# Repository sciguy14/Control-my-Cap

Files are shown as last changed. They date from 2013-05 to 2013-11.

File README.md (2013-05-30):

CONTROL MY CAP
==============
Learn more about this system on my website: http://www.jeremyblum.com/portfolio/control-my-cap  
Watch a video demo of this system: http://www.youtube.com/watch?v=23_6IZ159EQ  
  
These are the open design files for my "Control My Cap" project, which enable crowd control of a high-intensity LED array mounted on my mortar board for my graduation from the Masters in Electrical and Computer Engineering Program at Cornell University.
  
The system is setup as follows:  
* A mobile-optimized website built using Jquery Mobile UI & a Python/MySQL backend sits on a cloud server.
* People visit the website and enter a twitter handle or name, plus a color (chosen from a palet).
* After picking a color, ajax calls are used to pass the information to a python script on the server via JSON messages.
* The python script on the cloud server adds information about the color request (ID, time, name, twitter_ID, and color) to a MySQL database that resides on the same cloud server.
* The graduate (that's me) is equipped with a 15V rechargable laptop battery, a high-intensity LED cap fixture, and a Raspberry Pi computer + LCD/button "Pi Plate" (the Wrist Interface)
* The Wrist interface is strapped to the graduate's wrist, and uses the LCD to show system status.  Operation modes can be adjusted with buttons on the unit.  The Wrist controller is running [Linux Occidentalis v0.2](http://learn.adafruit.com/adafruit-raspberry-pi-educational-linux-distro/occidentalis-v0-dot-2).  It also has a Wifi USB dongle, and a USB-Serial Adapter attached.
* The USB-Serial adapter cable runs up the sleeve from the Wrist Computer to the LED array on the cap to send control commands (the cap runs an ATmega listening for Serial commands).
* Power runs from the wrist computer to the laptop battery pack where a 5V regulated supply is available.
* The battery pack is in a small drawstring backpack. It sends power the to wrist interface (5V), and up to the cap (15V).
* The wrist interface auto-runs a control program on boot.  It constantly checks the remote MySQL database, and updates its internal queue when the MySQL database gets updated.  The queue is then used to send color commands to the cap. When a new color is received, and it has not been tweeted yet, the wrist computer sends out a tweet and updates the database state variable.
  
Note:  I am opening as many files as I can.  Part of my design utilizes firmware and electronics from a another project of mine that I cannot (yet) open source.  You can sign up to learn more about it here: http://www.sunnlight.com.  

Included Folders and Repo Contents
----------------------------------
### /3D_printed_cap_holder
These are the 3D-printed design files for the mechanical PCB holder that sits on my head.
### /3D_printed_wrist_mount
These are the 3D-printed design files for the wrist-mounting unit. This enclosure houses and protects a Raspberry Pi, as well as an Adafruit LCD Pi-Plate.
### /mobile_site
These are the files that power the www.controlmycap.com mobile site. The front end is HTML+CSS+Jquery Mobile UI. It talks to a Python/MySQL backend via JSON AJAX calls.
### /wrist_controller
These are the linux scripts that run on the Raspberry Pi that is strapped to my wrist.

License
-------
This work is licensed under a Creative Commons Attribution-ShareAlike 3.0 Unported License.  
Please share improvements or remixes with the community, and attribute me (Jeremy Blum, http://www.jeremyblum.com) when reusing portions of my code.
http://creativecommons.org/licenses/by-sa/3.0/deed.en_US

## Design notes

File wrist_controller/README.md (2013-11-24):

CONTROL MY CAP: Wrist Controller
================================
These are the files that run on the wrist computer. They coordainte the MySQL data, tweeting, controlling the LCD, reading the buttons, and sending serial commands to the light. 

Usage Notes
-----------
* I am running Linux Occidentalis v0.2 (It has I2C support already set-up).
* Place all these files in `/home/pi/cap`.
* Create a local MySQL database table called "config" with just two columns:
    * option(Varchar 16)
    * value (Varchar 16)
* In the "config" table, create three entries and load them with the defaults:
    * option = "brightness", value = "10"
	* option = "mode", value = "9"
	* option = "last_tweeted", value = "0"
* Sign up for a Twitter Dev account, and [create an API app](https://dev.twitter.com/apps).  Give it read/write access and note the `Consumer Key` and the `Consumer Secret`.
* Rename 'sample_config.py' to 'config.py' and set the variables to the information for your MySQL Schema. Set the key info for your Twitter App.
* Make sure the `pi` user has access to the i2c bus.  By default, you must be `root`. To do this, run: `sudo adduser pi i2c`. You will need to logout and login for this to take effect.
* You need to SSH into the wrist computer and run command.py one time to complete the steps for twitter OAuth authentication.  You only need to do this once.
* `/etc/rc.local` is used to initialize the system at boot.  Add the following code to `/etc/rc.local` before `exit 0` (You need to be `root` to edit this file):  

        #Init SQL database mode to "off" state
		/home/pi/cap/boot.py

		#Get the Commander Program running the in the background.
		/home/pi/cap/command.py >>/var/www/log.txt &

		#Disable RTS for USB0 Serial Device, if successful, start program
		(stty -F /dev/ttyUSB0 -hup && /home/pi/cap/cap.py) || /home/pi/cap/fail.py

First, this boot script will set the mode to "off", incase you are operating off a wifi network. Then, `rc.local` will start running the command program in the background.  It will log to a txt file that you can view from a browser on a device connected to the same network.  This is useful for spotting bugs. Then, `rc.local` will disable RTS on the USB Serial line (This prevents the cap circuit board from reseting everytime the pySerial objects connnects). If that succeeds, the main control program is started. Otherwise, the failure is indicated by the fail script.
* You will want the computer to automatically associate with a wifi network on boot. Follow [these instructions](http://www.geeked.info/raspberry-pi-add-multiple-wifi-access-points/) to install wpa-supplicant, run it in background mode at boot, and generate the pre-shared keys for your WPA-protected networks.

Necessary Packages
------------------
You will need to have the following packages installed.
* [pySerial](http://pyserial.sourceforge.net/)
* [Python MySQLdb](http://sourceforge.net/projects/mysql-python/)
* [Adafruit Raspberry Pi Libraries](https://github.com/adafruit/Adafruit-Raspberry-Pi-Python-Code) (Necessary files for I2C LCD Pi Plate Communications are already included here)
* [Python Twitter Tools](http://mike.verdone.ca/twitter/)

Attribution for Packaged Library Files
--------------------------------------
### Adafruit Python Libraries
Adafruit invests time and resources providing this open source code, please support Adafruit and open-source hardware by purchasing products from Adafruit!  
Written by Limor Fried, Kevin Townsend and Mikey Sklar for Adafruit Industries. BSD license, all text above must be included in any redistribution

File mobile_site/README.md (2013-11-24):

CONTROL MY CAP: Mobile Site
======================================
These are the files that power the mobile site.  They are running on a remote cloud server. Python 2.6 is used, and the MySQLdb library must be installed. 

Usage Notes
-----------
To use this, you will need to rename 'sample_config.py' in the cgi-bin to 'config.py' and set the variables to the information for your MySQL Schema.  
  
You should have a MySQL database table setup as follows:
* index (unsigned, autoincrementing & primary key)
* time (MySQL timestamp default)
* name (Varchar, Length 16)
* twitter (Varchar, Length 16)
* color (char, Length 7)

Useful Links & Resources
------------------------
* [JQuery Mobile](http://jquerymobile.com/)
* [JQUery MiniColors](https://github.com/claviska/jquery-miniColors)
* [Python MySQLdb](http://sourceforge.net/projects/mysql-python/)

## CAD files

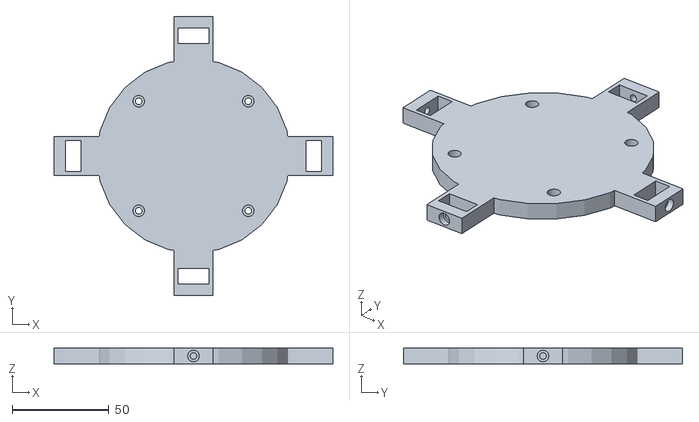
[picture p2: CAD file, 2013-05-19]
3D_printed_cap_holder/cap_base.stl
144.0 x 144.0 x 8.00

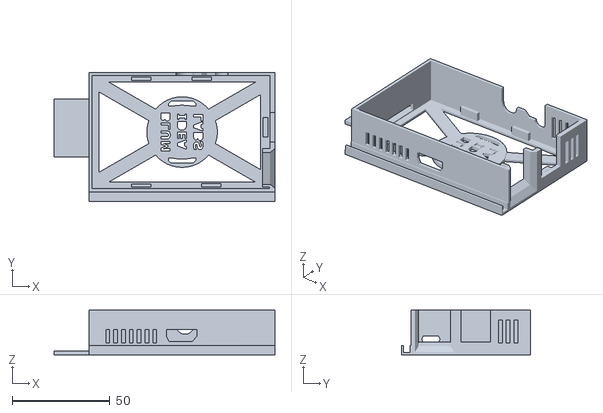
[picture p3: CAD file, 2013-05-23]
3D_printed_wrist_mount/pi_holder/bottom.stl
113.0 x 66.1 x 22.8

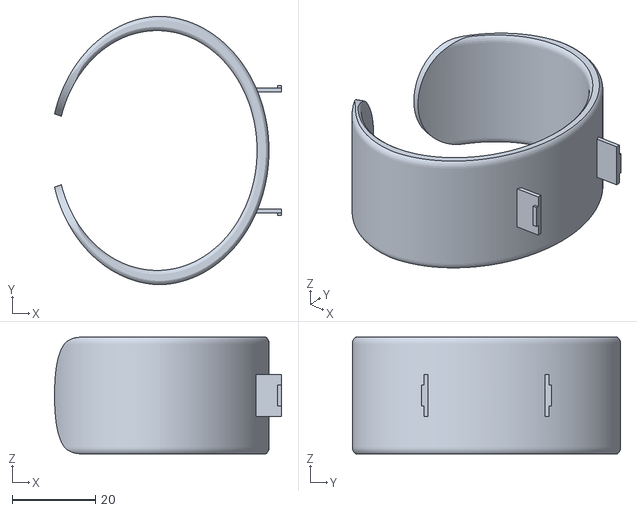
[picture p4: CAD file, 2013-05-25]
3D_printed_wrist_mount/wrist_clip/wrist_clip (repaired).stl
54.5 x 64.5 x 28.1

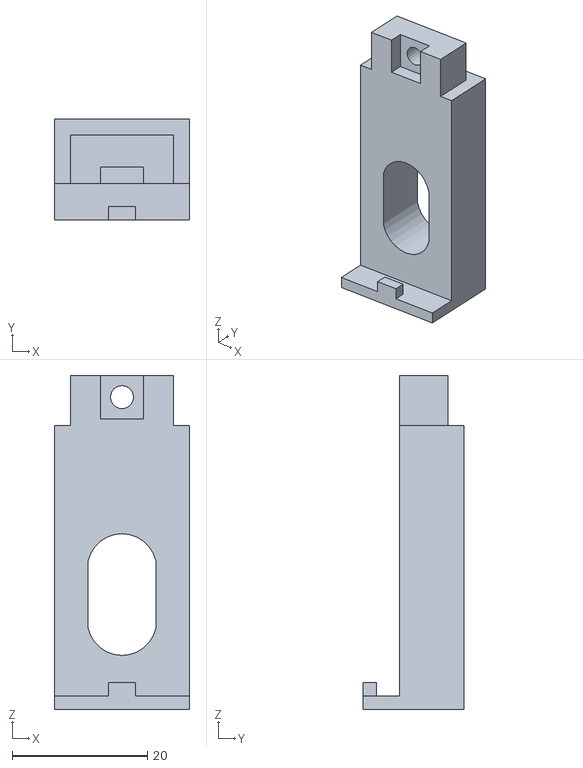
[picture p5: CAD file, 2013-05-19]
3D_printed_cap_holder/cap_clip.stl
20.0 x 15.0 x 49.4

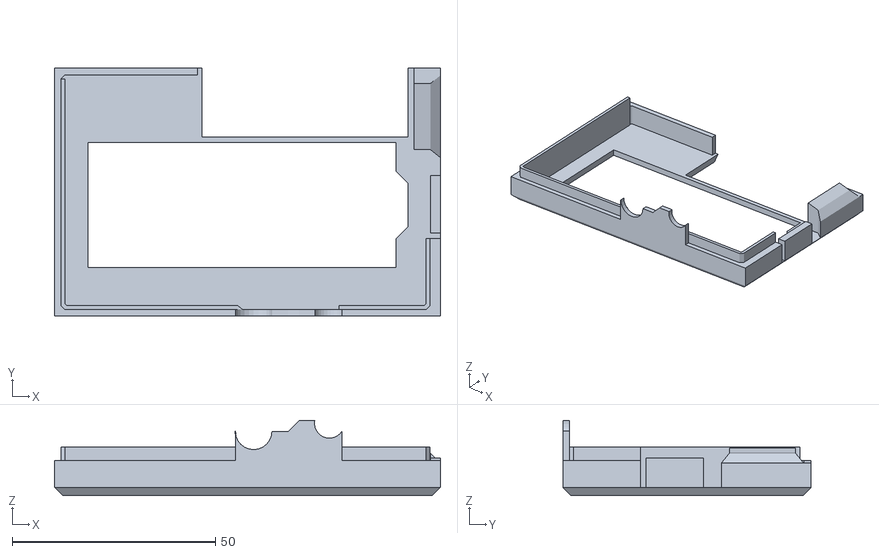
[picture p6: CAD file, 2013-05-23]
3D_printed_wrist_mount/pi_holder/top.stl
95.0 x 61.1 x 18.5

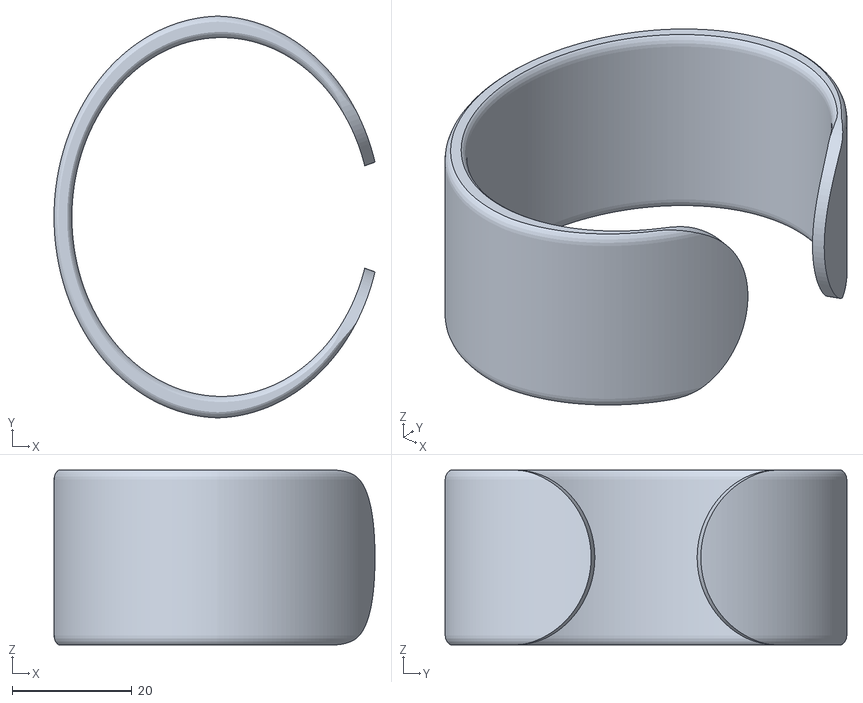
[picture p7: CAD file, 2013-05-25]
3D_printed_wrist_mount/wrist_clip/flatOpenBracelet.stl
53.7 x 67.2 x 29.2

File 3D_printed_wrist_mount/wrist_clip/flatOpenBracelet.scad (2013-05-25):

/*
 * flatOpenBracelet.scad
 * 
 * Written by aubenc @ Thingiverse
 *
 * http://www.thingiverse.com/thing:17083
 *
 *	Licensed under the Creative Commons Public Domain license
 *
 * Usage:
 *
 *		Features:
 *
 *		1. A central section for the texture of your bracelet.
 *
 *		2. Texture section surronded by two flat sections.
 *
 *		3.	Almost rounded edges. Rounded with a little flat to make it easy
 *			to stick to the build platform, the size of the flat is determined
 *			by your desired overhang angle.
 *
 *		4. Asimetrical construction (thinner at the opening side) for a
 *			texture fadding effect.
 *
 *		Set the parameters to the desired values...
 *
 *			For a circular  Bracelet set both "yas" and "xas" to
 *			the same value.
 *
 *			Add a module with the design of your texture and use the
 *			boolean intersection() for your module and envelope() module.
 */


/* *************** Parameters *********************************************** */

yas=60;		// Y axis inner diameter of the ring/bracelet
xas=50;		// X axis inner diameter of the ring/bracelet
thg=1.5;		// Texture Cut Depth
twd=20;		// Texture Width
dfw=1.5;		// Flat non textured width at each end
mwt=2.1;		// Minimum Wall Thickness
rlf=60;		// Angle to start the roundness for the edges
osz=20;		// Opening size


				// Don't set the following parameter to zero!
				// (unless you enjoy running into division by zero errors)
				//
res=1;		// Ressolution, +/- face each [value]mm of perimeter 
				// 	High value for a quicker rendering.
				//		Low value for a smooth finishing.


/* *************** Computed / Hardcoded ************************************* */

rid=yas;						// Ring inner diameter
rod=rid+2*(mwt+thg);		// Ring outer diameter
rwd=twd+2*dfw;				// Ring width
tcr=(pow(thg,2)+pow(twd/2,2))/2/thg;	// Texture carve circle radius
tco=rod/2+tcr-thg;		//	Texture carve circle traslation
rhg=(mwt+thg)*sin(rlf);	// Rounded edge ring height
tth=twd+2*(thg+rhg);		// Total height
fct=4*round(rod*PI/res/4);		// Facets for the bracelet circle

echo("Total Height: ",tth);


/* *************** Modulers ************************************************* */

	envelope();


/* *************** Code ***************************************************** */

module envelope()
{
	scale([xas/yas,1,1])
	intersection()
	{
		bracelet_ring();
		raw_shape();
		texture_fadding();
	}
}

module bracelet_ring()
{
	difference()
	{
		rounded_block();

		translate([0,0,-0.1])
		cylinder(h=tth+0.2, r=rid/2, $fn=fct, center=false);
	}
}

module raw_shape()
{
	olf=asin(osz/(2*sqrt(pow(osz/2,2)+pow(rod/2,2))));

	x0=0;						x1=rod/2+0.1;
	y0=tth/2/cos(olf);	y1=y0+rod/2*tan(olf);

	translate([0,0,tth/2])
	if( osz == 0 )
	{
		cube(size=[rod,rod,tth], center=true);
	}
	else
	{
		union()
		{
			difference()
			{
				cube(size=[rod,rod,tth], center=true);

				linear_extrude(height=tth+0.2, center=true, convexity=10)
				polygon(points=[ [x0,y0],[x1,y1],[x1,-y1],[x0,-y0] ],
							paths=[ [0,1,2,3] ]);
			}

			for(i=[-1,1])
			{
				rotate([0,90,i*olf])
				translate([0,i*tth/2,0])
				cylinder(h=rod, r=tth/2, $fn=4*round(tth*PI/res/4), center=false);
			}
		}
	}
}

module texture_fadding()
{
	translate([-thg,0,0])
	union()
	{
		rounded_block();

		cylinder(h=tth, r=(rod+rid)/4, $fn=fct, center=false);
	}
}

module rounded_block()
{
	union()
	{
		translate([0,0,rhg/2]) rounded_edge();

		translate([0,0,rhg/2])
		cylinder(h=tth-rhg, r=rod/2, $fn=fct, center=false);

		translate([0,0,tth-rhg/2]) rounded_edge();
	}
}

module rounded_edge()
{
	intersection()
	{
		cube(size=[rod+1,rod+1,rhg], center=true);

		rotate_extrude($fn=fct, convexity=10)
		translate([(rid+mwt+thg)/2,0,0])
		circle(r=(mwt+thg)/2, $fn=(rod-rid)*PI/res);
	}
}

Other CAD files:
3D_printed_wrist_mount/wrist_clip/wrist_clip.stl
3D_printed_cap_holder/cap_clip.skp
3D_printed_wrist_mount/pi_holder/wrist_mount.skp
3D_printed_wrist_mount/wrist_clip/wrist_clip.skp

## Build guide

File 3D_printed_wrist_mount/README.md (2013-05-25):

CONTROL MY CAP: 3D-Printed Wrist Mount
======================================
These are the 3D printed parts for holding the control interface on my wrist. The case holds both a Raspberry Pi and the Adafruit [LCD Pi Plate](http://www.adafruit.com/products/1115). I've added a cutout for the buttons/LCD, as well as a support tray for the SD card to protect it.  There is ventilation for the Pi, and two strap mounting points on the bottom. A wrist clip snaps into these strap mounting points as well, as is included in the wrist_clip folder. A channel allows the micro USB power cable to be routed in the same direction as the USB-serial cable that goes to the hat.  This is designed for the wearer's right wrist. This design has been printed and tested successfully on a MakerBot Replicator Dual, using PLA.  
  
The Pi Case is based on this design: http://www.thingiverse.com/thing:23430
The Wrist Mount is based on this design: http://www.thingiverse.com/thing:17083

Folders
-----
* pi_holder: The design files for the case that holds the Pi (top and bottom pieces)
* wrist_clip: A braclet that snaps onto the Pi holder to attach it to your wrist

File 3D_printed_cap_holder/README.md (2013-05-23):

CONTROL MY CAP: 3D-Printed Cap Holder
=====================================
These are the 3D printed parts for holding the LED Board on my cap, along with the light diffuser. This design has been printed and tested successfully on a MakerBot Replicator Dual, using PLA.
  
Unfortunately, I cannot release the design files or firmware for the PCB at this time. It is about 110mm diameter.

Files
-----
* cap_base.skp: Base print Sketchup Design File
* cap_base.stl: Base print STL export
* cap_clip.skp: Single diffuser clip Sketchup Design File (Four needed)
* cap_clip.stl: Diffuser clip STL export (Four need)
* cap_holder.thing: MakerBot MakerWare Thing File for build tray
* cap_holder.x3g: MakerBot Replicator Dual Print File

Additional Hardware
-------------------
* Camera Flash Diffuser (http://www.amazon.com/Gary-Fong-INVDOM-Lightsphere-Replacement/dp/B00119MWPK/)
* 8 10mm M3 Socket Cap bolts (McMaster Part: 91292A113)
* 12 M3 nuts (McMaster Part: 90592A009)
* 4 31mm Threaded M3 Male-Female Hex Standoffs (McMAster Part: 98952A122)

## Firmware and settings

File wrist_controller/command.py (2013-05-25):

#!/usr/bin/python
# Serial Command Script

####
# IMPORT LIBRARIES AND CONFIGS
####
import MySQLdb as mdb
import serial, math, urllib2, json, os
from config import *
from time import time
from twitter import *

####
# FUNCTIONS
####

def hex_to_rgb(value):
    value = value.lstrip('#')
    lv = len(value)
    return tuple(int(value[i:i+lv/3], 16) for i in range(0, lv, lv/3))


####
# MAIN PROGRAM
####
fade_time = 1000 #ms
buffer_time = 2  #seconds
last_mode = -1
last_scale = 0
rainbow_state = 0
web_state = 0
last_tweeted = 1
last = int(time())

rainbow_cycle = [
                    (0.0,0.0,0.0,0.0),
                    (255.0,0.0,0.0,0.0),
                    (255.0,255.0,0.0,0.0),
                    (255.0,255.0,255.0,0.0),
                    (0.0,255.0,255.0,255.0),
                    (0.0,255.0,255.0,0.0),
                    (0.0,0.0,255.0,0.0),
                    (255.0,0.0,255.0,0.0),
                    (255.0,0.0,255.0,255.0),
                    (0.0,0.0,255.0,255.0),
                    (0.0,0.0,0.0,255.0),
                    (0.0,255.0,0.0,255.0),
                    (255.0,255.0,0.0,255.0),
                    (0.0,255.0,0.0,0.0)
                ]
rainbow_max_index = len(rainbow_cycle)-1

web_cycle = [
                    (0.0,0.0,0.0),
                    (0.0,0.0,0.0),
                    (0.0,0.0,0.0),
                    (0.0,0.0,0.0),
                    (0.0,0.0,0.0),
                    (0.0,0.0,0.0),
                    (0.0,0.0,0.0),
                    (0.0,0.0,0.0),
                    (0.0,0.0,0.0),
                    (0.0,0.0,0.0)
            ]
web_max_index = len(web_cycle)-1

twitter_set = False

while True:
    # Look at the local database to determine the operation mode and brightness.
    local_conn = mdb.connect(local_host, local_user, local_passwd, local_db)
    with local_conn:
        cur = local_conn.cursor()
        sqlstring = "SELECT `value` FROM config WHERE `option` = 'mode'"
        cur.execute(sqlstring)
        mode = int(cur.fetchone()[0])
        sqlstring = "SELECT `value` FROM config WHERE `option` = 'brightness'"
        cur.execute(sqlstring)
        scale = (float(cur.fetchone()[0]))/100.0
        sqlstring = "SELECT `value` FROM config WHERE `option` = 'last_tweeted'"
        cur.execute(sqlstring)
        last_tweeted = int(cur.fetchone()[0])
    local_conn.close()

    #If we're in web mode for the first time, authenticate w/ Twitter Oauth
    if mode == 0 and twitter_set == False:
        MY_TWITTER_CREDS = os.path.expanduser('/home/pi/.my_app_credentials')
        if not os.path.exists(MY_TWITTER_CREDS):
            oauth_dance("Jeremy's Cap", CONSUMER_KEY, CONSUMER_SECRET, MY_TWITTER_CREDS)
        oauth_token, oauth_secret = read_token_file(MY_TWITTER_CREDS)
        twitter = Twitter(auth=OAuth(oauth_token, oauth_secret, CONSUMER_KEY, CONSUMER_SECRET))
        twitter_set = True


    # If we're in web mode, update the web cycle matrix
    if mode == 0:
        data = urllib2.urlopen('http://controlmycap.com/cgi-bin/retrieve.py').read()
        data = json.loads(data);
        for i in range(len(web_cycle)):
            data[i][2] = str(data[i][2])
            data[i][3] = str(data[i][3])
            data[i][4] = str(data[i][4])
            rgb = hex_to_rgb(data[i][4])
            web_cycle[i] = list(web_cycle[i])
            web_cycle[i][0] = float(rgb[0])
            web_cycle[i][1] = float(rgb[1])
            web_cycle[i][2] = float(rgb[2])
            #tweet it if this is being added for the first time!
            if data[i][0] > last_tweeted:
                #tweet it
                if data[i][3] == "":
                    name = data[i][2]
                else:
                    name = data[i][3]
                hex_color = data[i][4]
                tweet = "Thanks " + name + "! I'm about to cycle to your color: " + hex_color + " (ID: " + str(data[i][0]) + ")"
                twitter.statuses.update(status=tweet)
                #update local database
                local_conn = mdb.connect(local_host, local_user, local_passwd, local_db)
                with local_conn:
                    cur = local_conn.cursor()
                    sqlstring = "UPDATE config SET `value`=" + str(data[i][0]) + " WHERE `option`='last_tweeted'"
                    cur.execute(sqlstring)
                local_conn.close()
    

    #If something has changed, issue an update to the cap!
    #If it's time for a rainbow update, do that.
    #If it's time for a web cycle update, do that.
    if mode != last_mode or scale != last_scale or (int(time()) >= last + buffer_time and (mode == 1 or mode == 0)):

        # Setup the Serial Port
        ser = serial.Serial('/dev/ttyUSB0', 57600, timeout=1)

        #Web-Controlled
        if mode == 0:
            if web_state > web_max_index:
                web_state = 0
            last = int(time())
            ser.write(".a:3:" + str(int(math.floor(web_cycle[web_state][0]*scale))) + "," + str(int(math.floor(web_cycle[web_state][1]*scale))) + "," + str(int(math.floor(web_cycle[web_state][2]*scale))) + ",0," + str(fade_time) + "\n")
            web_state = web_state + 1

        #Rainbow
        elif mode == 1:
            if rainbow_state > rainbow_max_index:
                rainbow_state = 0
            last = int(time())    
            ser.write(".a:3:" + str(int(math.floor(rainbow_cycle[rainbow_state][0]*scale))) + "," + str(int(math.floor(rainbow_cycle[rainbow_state][1]*scale))) + "," + str(int(math.floor(rainbow_cycle[rainbow_state][2]*scale))) + "," + str(int(math.floor(rainbow_cycle[rainbow_state][3]*scale))) + "," + str(fade_time) + "\n")
            rainbow_state = rainbow_state + 1

        #Red
        elif mode == 2:
            ser.write(".a:3:" + str(int(math.floor(255.0*scale))) + ",0,0,0," + str(fade_time) + "\n")
            
        #Green
        elif mode == 3:
            ser.write(".a:3:0," + str(int(math.floor(255.0*scale))) + ",0,0," + str(fade_time) + "\n")
        #Blue
        elif mode == 4:
            ser.write(".a:3:0,0," + str(int(math.floor(255.0*scale))) + ",0," + str(fade_time) + "\n")
        #White
        elif mode == 5:
            ser.write(".a:3:0,0,0," + str(int(math.floor(255.0*scale))) + "," + str(fade_time) + "\n")
        #Teal
        elif mode == 6:
            ser.write(".a:3:0," + str(int(math.floor(255.0*scale))) + "," + str(int(math.floor(255.0*scale))) + ",0," + str(fade_time) + "\n")
        #Purple
        elif mode == 7:
            ser.write(".a:3:" + str(int(math.floor(255.0*scale))) + ",0," + str(int(math.floor(255.0*scale))) + ",0," + str(fade_time) + "\n")
        #Orange
        elif mode == 8:
            ser.write(".a:3:" + str(int(math.floor(255.0*scale))) + "," + str(int(math.floor(255.0*scale))) + ",0,0," + str(fade_time) + "\n")
        #Off
        elif mode == 9:
            ser.write(".a:3:0,0,0,0," + str(fade_time) + "\n")

        #Close the Serial port
        ser.close()

        #Update tracking variables
        last_mode = mode
        last_scale = scale

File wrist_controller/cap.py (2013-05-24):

#!/usr/bin/python
# Menu and Control Interface

####
# IMPORT LIBRARIES AND CONFIGS
####
import MySQLdb as mdb
from config import *
from time import sleep
from Adafruit_CharLCDPlate import Adafruit_CharLCDPlate
from subprocess import check_output
import socket, os

####
# FUNCTIONS
####


# FUNCTION TO FACILIATE MENU SCROLLING
def update_menu(index_selected, num_items, menu_items):
    lcd.clear()
    if index_selected % 2 == 0 and num_items>(index_selected+1):
        lcd.message('>' + menu_items[index_selected][1:] + '\n' + menu_items[index_selected+1])
    elif index_selected % 2 == 0 and num_items<=(index_selected+1):
        lcd.message('>' + menu_items[index_selected][1:])
    else:
        lcd.message(menu_items[index_selected-1] + '\n>' + menu_items[index_selected][1:])

####
# TABLES
####

top_menu =  [
                ' Cap Mode',
                ' Cap Brightness',
                ' Toggle Bklight',
                ' Status'
            ]

mode_menu = [
                ' Web-Controlled',
                ' Rainbow',
                ' Red',
                ' Green',
                ' Blue',
                ' White',
                ' Teal',
                ' Purple',
                ' Orange',
                ' Off'
            ]



brightness_screens =  [
                        'Cap Brightness:\n#            10%',
                        'Cap Brightness:\n##           20%',
                        'Cap Brightness:\n###          30%',
                        'Cap Brightness:\n####         40%',
                        'Cap Brightness:\n#####        50%',
                        'Cap Brightness:\n######       60%',
                        'Cap Brightness:\n#######      70%',
                        'Cap Brightness:\n########     80%',
                        'Cap Brightness:\n#########    90%',
                        'Cap Brightness:\n##########  100%',
                      ]


####
# MAIN PROGRAM
####

# Initialize the LCD plate.  Should auto-detect correct I2C bus.  If not,
# pass '0' for early 256 MB Model B boards or '1' for all later versions
lcd = Adafruit_CharLCDPlate()

# Clear display and show greeting, pause 2 secs
lcd.clear()
lcd.backlight(lcd.ON)
backlight_state = 1
lcd.message("Control-my-Cap\nWrist Interface")
sleep(2)

# THE FOLLOWING SCREEN STATES EXIST
# top:          This is the top-level Menu.
# mode:         This is menu for selecting the cap operation mode from a list
# modeConfirm:  This is the confirmation screen for the mode selection
# brightness:   This is the brightness setting screen
# status:       This is the status monitoring screen

# We started at the top-level menu
state = 'top'

looping = True
top_menu_pointer = 0
while looping:
    lcd.clear()
    sleep(.3)
    if  state == 'top':
        top_menu_length = len(top_menu)
        update_menu(top_menu_pointer, top_menu_length, top_menu) 
        waiting = True
        while waiting:
            if lcd.buttonPressed(lcd.UP) and top_menu_pointer != 0:
                top_menu_pointer = top_menu_pointer - 1
                update_menu(top_menu_pointer, top_menu_length, top_menu)
                sleep(.3)
            elif lcd.buttonPressed(lcd.DOWN) and top_menu_pointer < top_menu_length-1:
                top_menu_pointer = top_menu_pointer + 1
                update_menu(top_menu_pointer, top_menu_length, top_menu)
                sleep(.3)
            elif lcd.buttonPressed(lcd.SELECT) or lcd.buttonPressed(lcd.RIGHT):
                if top_menu_pointer == 0:
                    state = 'mode'
                    waiting = False
                elif top_menu_pointer == 1:
                    state = 'brightness'
                    waiting = False
                elif top_menu_pointer == 2:
                    if backlight_state == 1:
                        lcd.backlight(lcd.OFF)
                        backlight_state = 0
                    else:
                        lcd.backlight(lcd.ON)
                        backlight_state = 1
                    waiting = True
                    sleep(.3)
                elif top_menu_pointer == 3:
                    state = 'status'
                    waiting = False
    
    elif state == 'mode':
        # get current mode setting from the local database
        local_conn = mdb.connect(local_host, local_user, local_passwd, local_db)
        with local_conn:
            cur = local_conn.cursor()
            sqlstring = "SELECT `value` FROM config WHERE `option` = 'mode'"
            cur.execute(sqlstring)
            sql_mode = int(cur.fetchone()[0])
        local_conn.close()
        mode_menu_pointer = sql_mode 
        mode_menu_length = len(mode_menu)
        update_menu(mode_menu_pointer, mode_menu_length, mode_menu) 
        waiting = True
        while waiting:
            if lcd.buttonPressed(lcd.UP) and mode_menu_pointer != 0:
                mode_menu_pointer = mode_menu_pointer - 1
                update_menu(mode_menu_pointer, mode_menu_length, mode_menu)
                sleep(.3)
            elif lcd.buttonPressed(lcd.DOWN) and mode_menu_pointer < mode_menu_length-1:
                mode_menu_pointer = mode_menu_pointer + 1
                update_menu(mode_menu_pointer, mode_menu_length, mode_menu)
                sleep(.3)
            elif lcd.buttonPressed(lcd.LEFT):
                state = 'top'
                waiting = False
                sleep(.3)
            elif lcd.buttonPressed(lcd.SELECT) or lcd.buttonPressed(lcd.RIGHT):
                state = 'modeConfirm'
                MODE = mode_menu_pointer
                waiting = False
    elif state == 'modeConfirm':
        lcd.message ('Setting Mode to:\n' + mode_menu[MODE][1:])
        local_conn = mdb.connect(local_host, local_user, local_passwd, local_db)
        with local_conn:
            cur = local_conn.cursor()
            sqlstring = "UPDATE config SET `value`=" + str(MODE) + " WHERE `option`='mode'"
            cur.execute(sqlstring)
        local_conn.close()
        lcd.clear()
        lcd.message ('Mode set to:\n' + mode_menu[MODE][1:])
        sleep(2)
        lcd.clear()
        lcd.message ('Press Select\nto go home.')
        waiting = True
        while waiting:
            if lcd.buttonPressed(lcd.SELECT):
                state = 'top'
                waiting = False
                sleep(.3)
    elif state == 'brightness':
        # get current brightness setting from the local database
        local_conn = mdb.connect(local_host, local_user, local_passwd, local_db)
        with local_conn:
            cur = local_conn.cursor()
            sqlstring = "SELECT `value` FROM config WHERE `option` = 'brightness'"
            cur.execute(sqlstring)
            brightness = int(cur.fetchone()[0])
        local_conn.close()
        lcd.clear
        lcd.message(brightness_screens[(brightness/10)-1])
        waiting = True
        while waiting:
            if lcd.buttonPressed(lcd.DOWN) and brightness > 10:
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

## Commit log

2013-05-19 Initial Commit, Holder 3D Designs Complete
    [cap_base.stl, cap_clip.skp, cap_clip.stl]
2013-05-23 Folders Reorganized, READMEs filled out in detail, added support for actual name if client does not use twitter, started development of Wrist Computer execution program, completed Wrist Computer 3D-p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
    [bottom.stl, cap_base.stl, cap_clip.skp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]
2013-05-23 Updates to functional of rc.local fail script, fixes #3
    [fail.py]
2013-05-25 Holy crap, it works.
    [bottom.stl, flatOpenBracelet.scad, flatOpenBracelet.stl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]
2013-05-25 Updated fit of wrist mount
    [wrist_clip (repaired).stl, wrist_clip.skp, wrist_clip.stl]
